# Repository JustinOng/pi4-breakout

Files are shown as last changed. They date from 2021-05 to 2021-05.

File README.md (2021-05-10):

Hat template from [xesscorp/RPi_Hat_Template](https://github.com/xesscorp/RPi_Hat_Template).

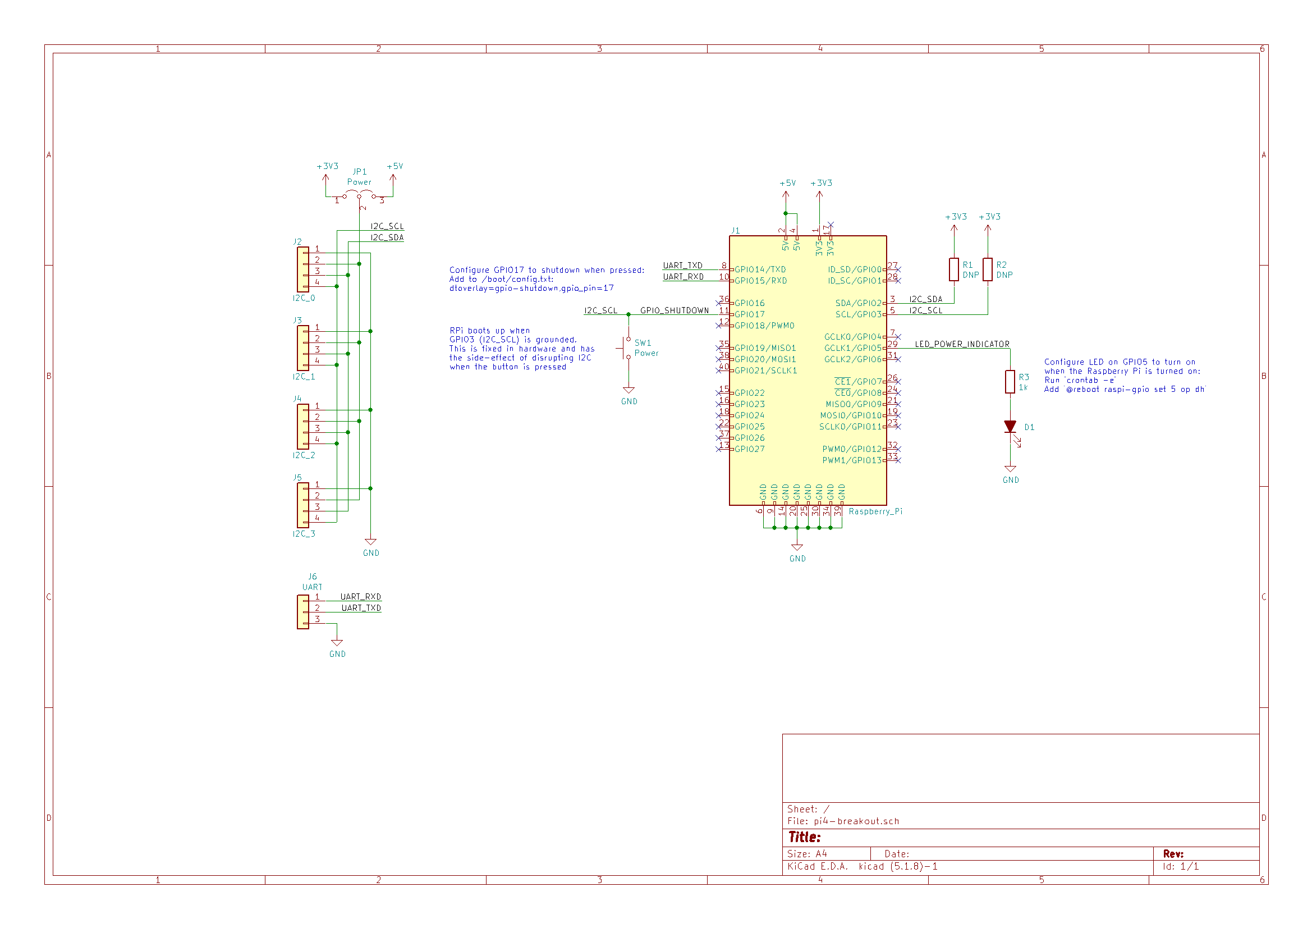
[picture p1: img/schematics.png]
schematics

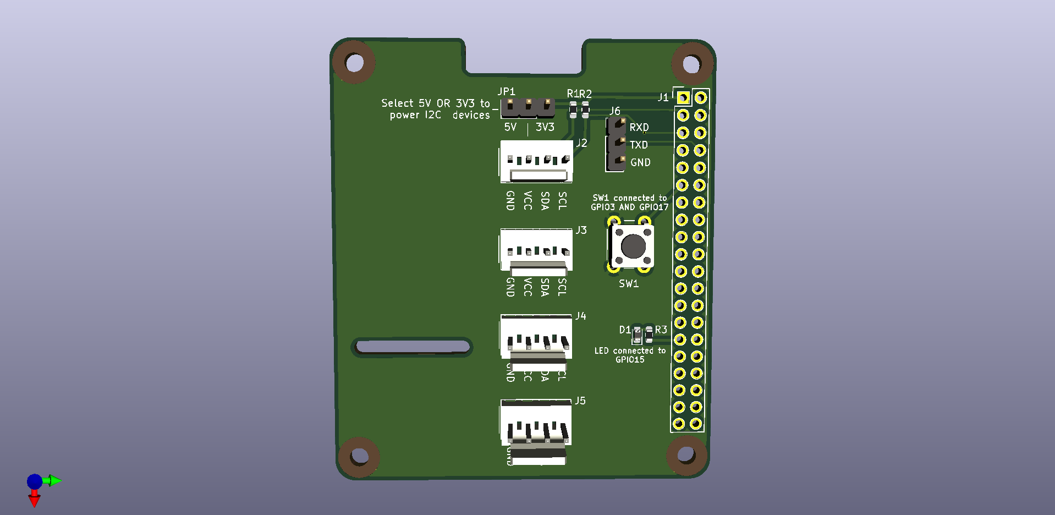
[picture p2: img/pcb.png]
pcb


- 4x connectors for I2C, silkscreen is for KF2510 (or KK 254)
- `GPIO3` (`I2C_SCL`) is connected to a button because grounding it will boot up the Pi after a shutdown (see [`WAKE_ON_GPIO`](https://www.raspberrypi.org/documentation/hardware/raspberrypi/bcm2711_bootloader_config.md))
- `GPIO17` is another arbitrary pin configured to shutdown the Pi when grounded (`dtoverlay=gpio-shutdown,gpio_pin=17` in `/boot/config.txt`)
- Surprisingly, connecting these two pins together and grounding them will startutp/shutdown the Pi, even though `SCL` is pulled low as part of I2C operation. There has been some anecdotal evidence [here](https://www.raspberrypi.org/forums/viewtopic.php?p=1565264#p1565264). Perhaps the deboucing on the shutdown overlay prevents it from triggering?
- `GPIO5` has an LED connected to it - configuring cron to set this pin `HIGH` on boot essentially makes this an indicator for whether the Pi is powered on (note that this pin turns off before the Pi is fully off - a Raspberry Pi 4B has been observed to still be blinking its `ACT` LED when `GPIO5` turns off). Probably a good idea to wait for the `ACT` LED to stop blinking before cutting power.

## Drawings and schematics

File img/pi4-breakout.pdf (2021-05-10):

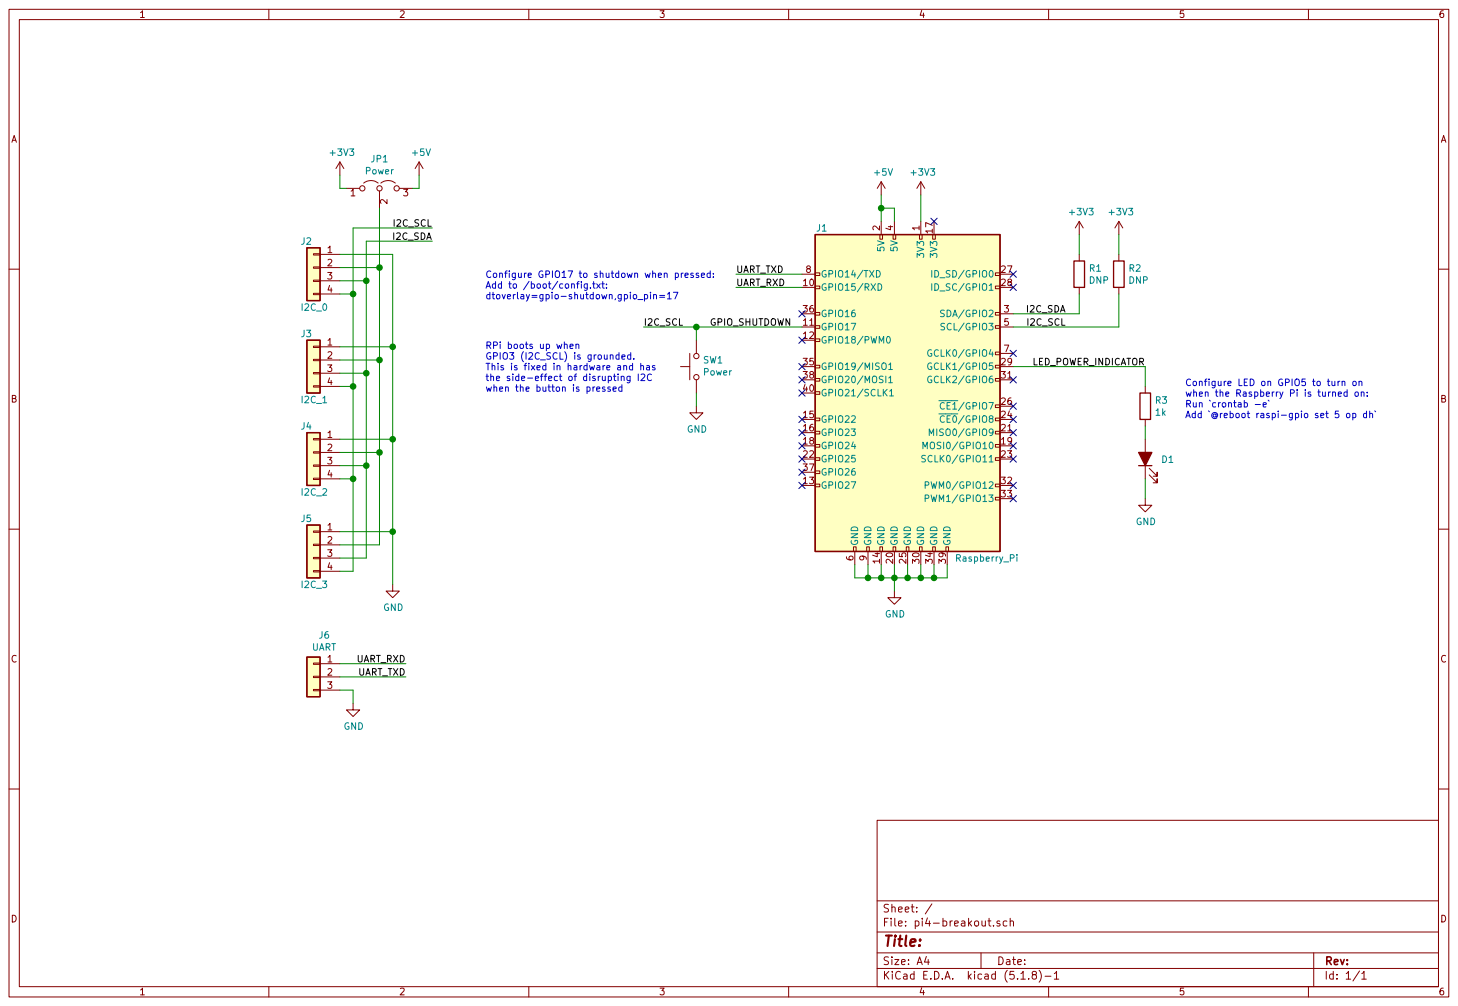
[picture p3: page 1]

Configure GPIO17 to shutdown when pressed:
Add to /boot/config.txt:
dtoverlay=gpio-shutdown,gpio_pin=17

RPi boots up when
GPIO3 (I2C_SCL) is grounded. This is fixed in hardware and has

the side-effect of disrupting I2C
when the button is pressed

Configure LED on GPIO5 to turn on
when the Raspberry Pi is turned on: Run `crontab -e` Add `@reboot raspi-gpio set 5 op dh`

File: pi4-breakout.sch Sheet: /
Id: 1/1 Title:

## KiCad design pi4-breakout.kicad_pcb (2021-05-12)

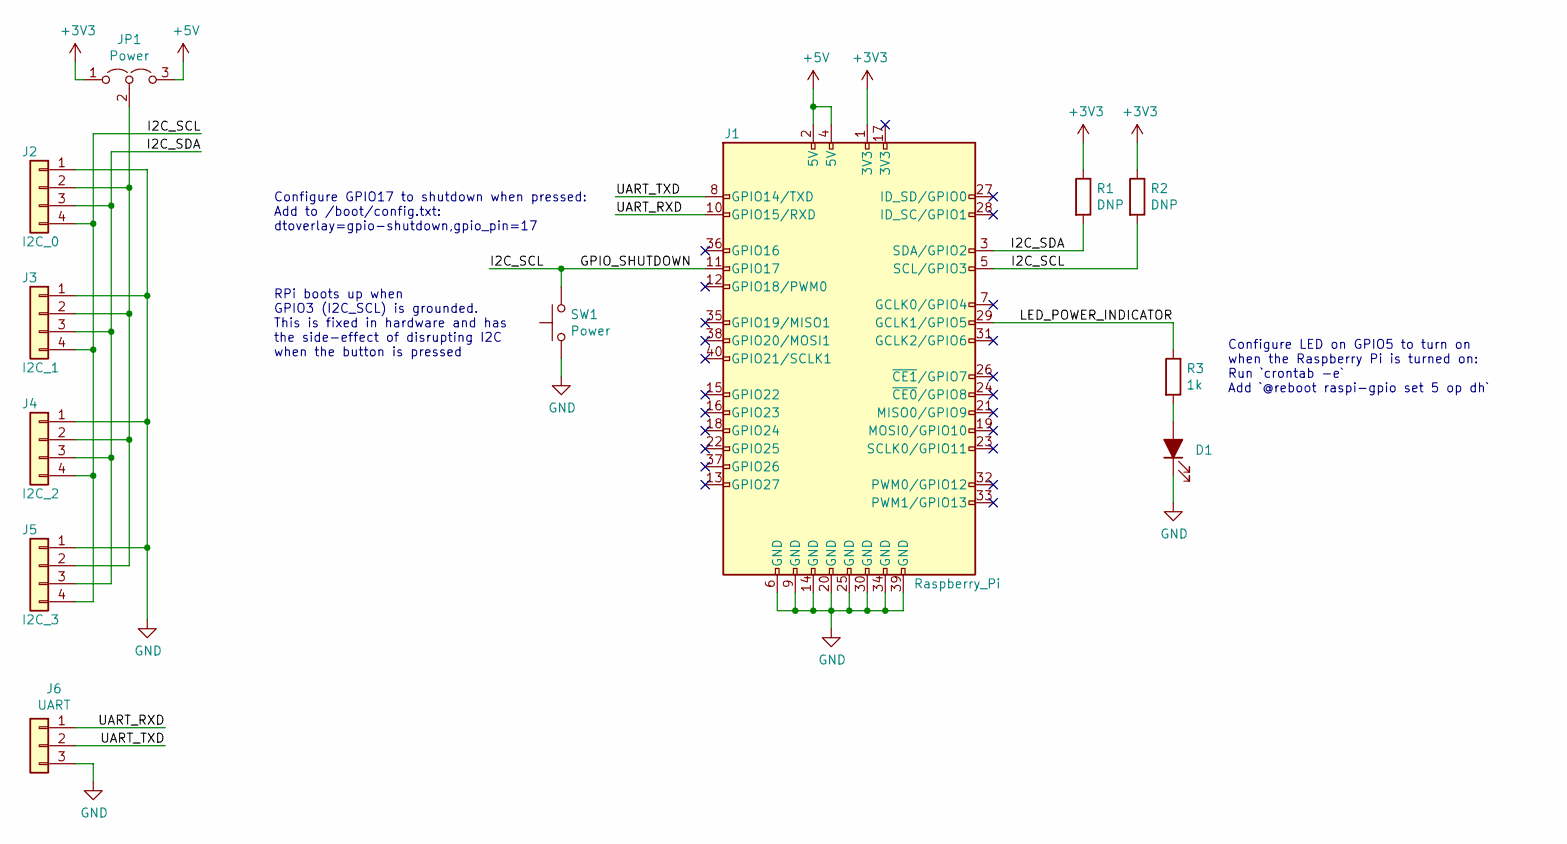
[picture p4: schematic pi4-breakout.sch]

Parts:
D1: LED_ALT; D_0603_1608Metric
J1: Raspberry_Pi; Pin_Header_Straight_2x20
J2: I2C_0; Molex_KK-254_AE-6410-04A_1x04_P2.54mm_Vertical
J3: I2C_1; Molex_KK-254_AE-6410-04A_1x04_P2.54mm_Vertical
J4: I2C_2; Molex_KK-254_AE-6410-04A_1x04_P2.54mm_Vertical
J5: I2C_3; Molex_KK-254_AE-6410-04A_1x04_P2.54mm_Vertical
J6: UART; PinHeader_1x03_P2.54mm_Vertical
JP1: Power; PinHeader_1x03_P2.54mm_Vertical
R1, R2: DNP; R_0603_1608Metric
R3: 1k; R_0603_1608Metric
SW1: Power; SW_PUSH_6mm

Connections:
+3V3: J1.1 (3V3), JP1.1 (A), R1.1, R2.1
+5V: J1.2 (5V), J1.4 (5V), JP1.3 (B)
/GPIO_SHUTDOWN: J1.5 (SCL/GPIO3), J1.11 (GPIO17), J2.4, J3.4, J4.4, J5.4, R2.2, SW1.2
/I2C_SDA: J1.3 (SDA/GPIO2), J2.3, J3.3, J4.3, J5.3, R1.2
/LED_POWER_INDICATOR: J1.29 (GCLK1/GPIO5), R3.1
/UART_RXD: J1.10 (GPIO15/RXD), J6.1
/UART_TXD: J1.8 (GPIO14/TXD), J6.2
GND: D1.1 (K), J1.6 (GND), J1.9 (GND), J1.14 (GND), J1.20 (GND), J1.25 (GND), J1.30 (GND), J1.34 (GND), J1.39 (GND), J2.1, J3.1, J4.1, J5.1, J6.3, SW1.1
unnamed: D1.2 (A), R3.2
unnamed: J2.2, J3.2, J4.2, J5.2, JP1.2 (C)

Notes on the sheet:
Configure GPIO17 to shutdown when pressed: Add to /boot/config.txt: dtoverlay=gpio-shutdown,gpio_pin=17
RPi boots up when GPIO3 (I2C_SCL) is grounded. This is fixed in hardware and has the side-effect of disrupting I2C when the button is pressed
Configure LED on GPIO5 to turn on when the Raspberry Pi is turned on: Run `crontab -e` Add `@reboot raspi-gpio set 5 op dh`

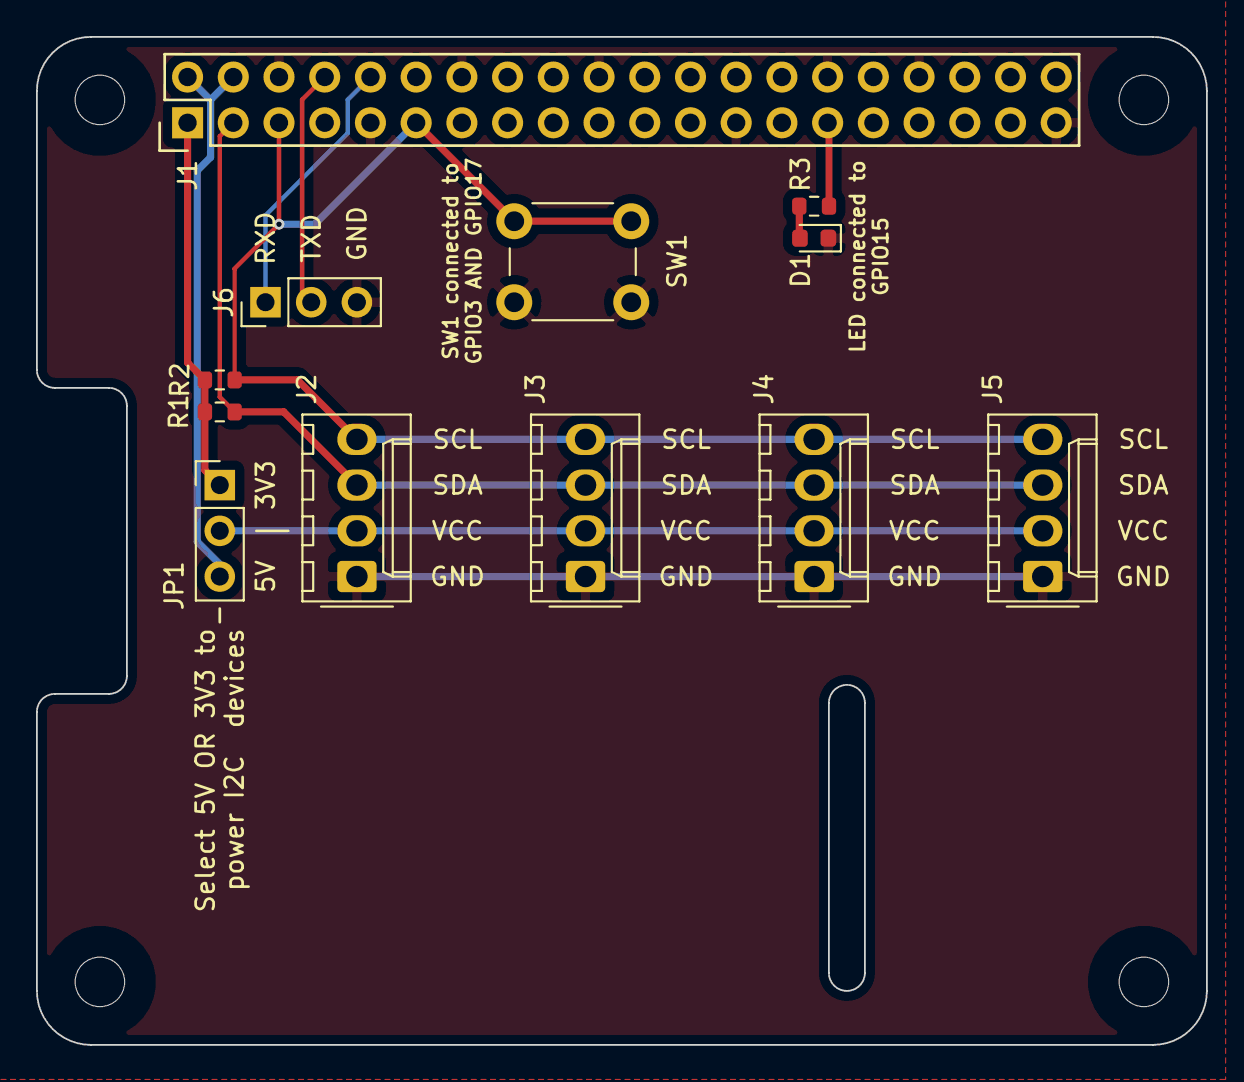
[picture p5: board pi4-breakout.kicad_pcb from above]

Board: 2 copper layers, 65.0 x 56.0 mm, 12 parts (0 on the bottom side), 10 nets.
